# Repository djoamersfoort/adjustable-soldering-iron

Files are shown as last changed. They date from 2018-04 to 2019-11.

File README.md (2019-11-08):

Adjustable Soldering Iron
=========================

An adjustable soldering iron with temperature display using Arduino.
It uses a TM1637Display driver to connect to a 4 digit display.
The temperature is acquired using the MAX6657 thermocouple interface.
Both of these require additional software found below:

- [TM1637 Display library by avischorp](https://github.com/avishorp/TM1637)
- [MAX6675 Thermocouple library by adafruit](https://github.com/adafruit/MAX6675-library)

To install them, download both repositories as a zip file,
and include them using the "Add .ZIP Library" option in the Arduino "Sketch" menu.
To keep the software easy to understand, some nice to have features are not included.

## Hardware

This project is aimed at members of DJO Amersfoort and therefor uses a fairly specific parts configuration.
The soldering iron used is a German 48W/230VAC VTSSC10N/SP made by Velleman.
The schematic is visible below, and is also provided as a pdf file.

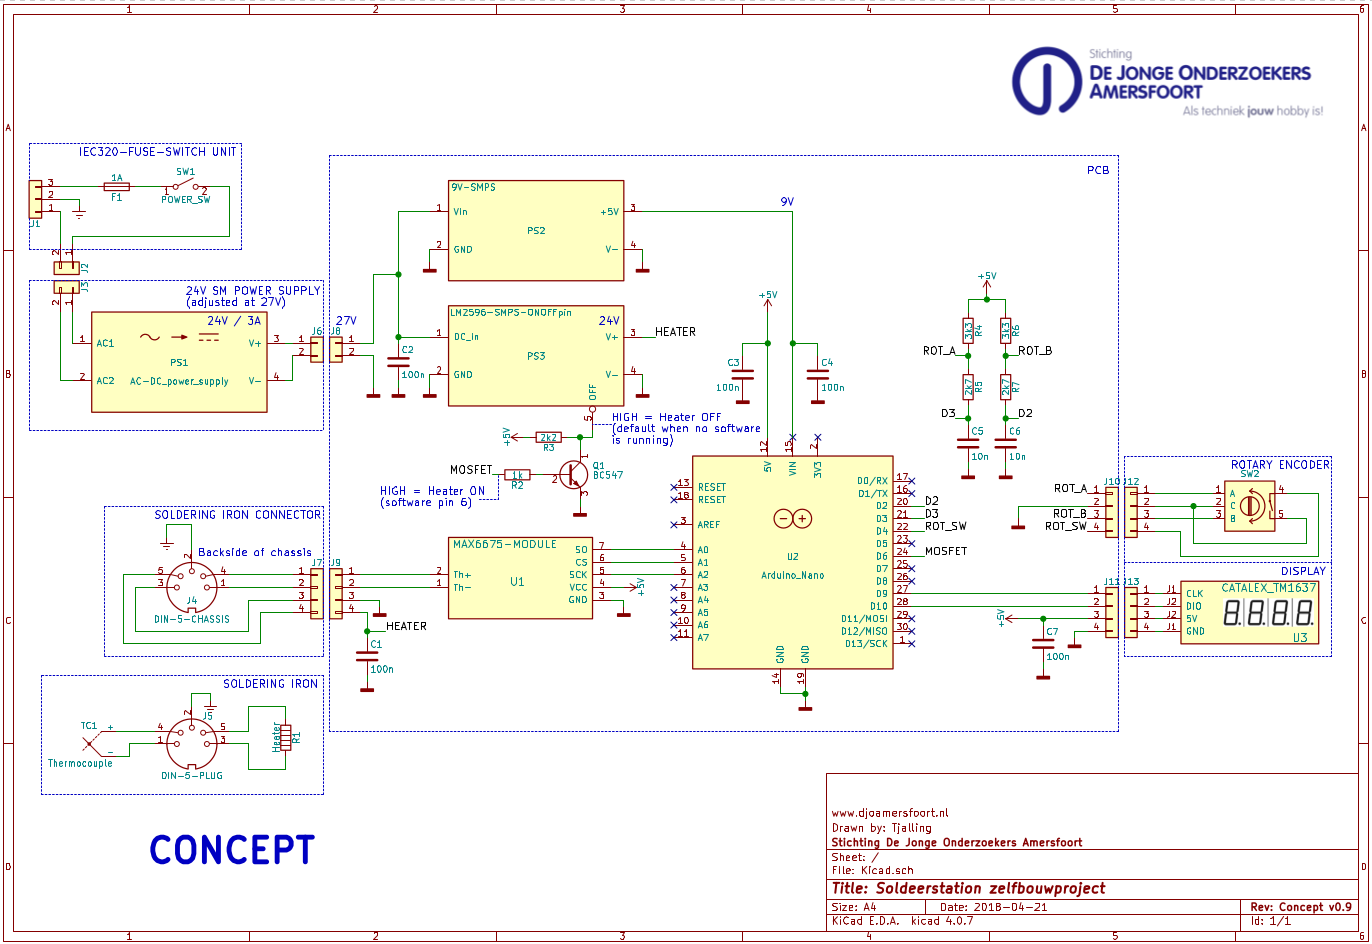
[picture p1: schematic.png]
schematic image


### 3D models

Inside the 3D models folder, there are models for both the case and the parts used for the soldering iron project.
You can use these to build and/or design your own case.

## License

Original concept by:

- Tjalling Brouwer

The software is made by:

- Jelmer van Arnhem ([Github](https://github.com/Jelmerro))
- Camiël vd Niet
- Sieuwe Elferink ([Github](https://github.com/sieuwe1))

The schematic is made by:

- Tjalling Brouwer

The 3d models are made by:

- Huub ([Github](https://github.com/Luxtech))
- Tjalling Brouwer

DJO Amersfoort holds the copyright for all files in this repository,
but they can be copied under the terms of the MIT license, see the LICENSE for details.

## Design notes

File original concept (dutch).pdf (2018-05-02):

Auteur: Tjalling Brouwer

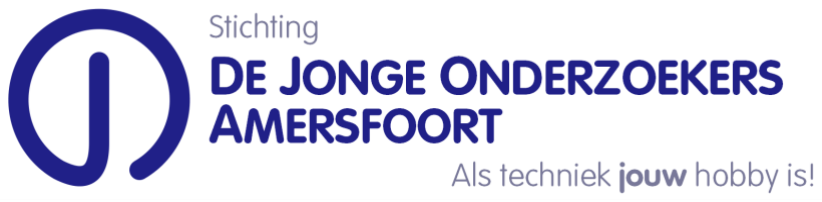
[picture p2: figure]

Oorspronkelijk idee ontwikkeld met Camiël en Hans en uitgewerkt met bijdragen zoals vermeld in Github documenten. Document versie: 2.3

### Idee voor een bouwproject soldeerstation met temperatuurregeling

Een soldeerstation is onmisbaar in een elektronicawerkplaats, of op een hobbytafel voor elektronicaliefhebbers en ICT doe-het-zelfers. Vooral een goed geregelde soldeerbout met voldoende vermogen biedt veel voordelen ten opzichte van de eenvoudige 230V boutjes of soldeerpistolen.

Velleman verkoopt soldeerstations opgebouwd met OEM onderdelen, die voor dit project een inspiratie zijn geweest. Want de soldeerbout zelf is gewoon los te koop. De kwaliteit van deze soldeerbouten is erg goed en er zit een temperatuursensor in. De punten zijn eenvoudig verkrijgbaar in verschillende diktes. Daarnaast zijn de kosten laag, zelfs bij lokale distributeurs.

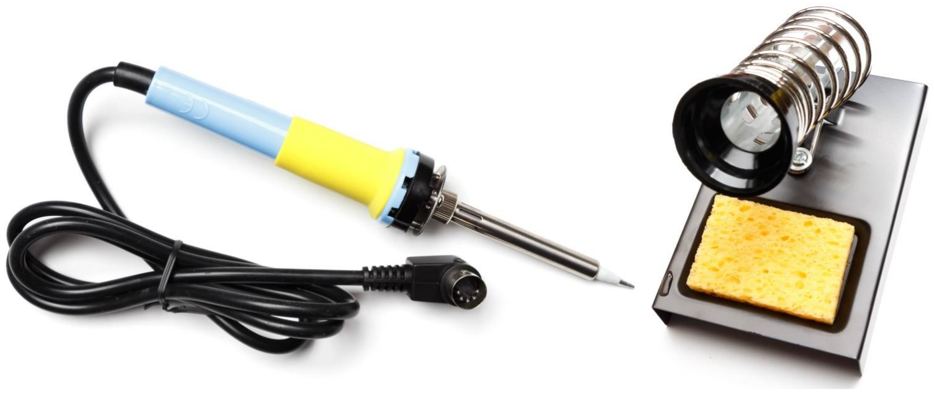
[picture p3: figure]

Er is echter nog wel wat nodig om hier een goed werkend soldeerstation van te maken. Dat maakt dit dan ook een leuk project voor op DJO. De volgende elementen moeten nog toegevoegd worden:

- Temperatuurregeling in een controller, bijvoorbeeld een Arduino
- Software voor de controller
- 24V voeding, een geschakelde voedingsmodule of een transformator (70W minimaal).
- Behuizing: geprint of lasercutter
- Randcomponenten, zoals display, potmeter/rotary switch, zekeringhouder(s), IEC 320 connector, DIN connector, MOSFET switch voor bout, PCB, etc

Controller software en hardware
Een Arduino NANO of UNO zou een goede controller kunnen zijn. Met behulp van begeleiders kunnen DJO leden dan zelf proberen de software te ontwerpen.

Aandachtspunten:

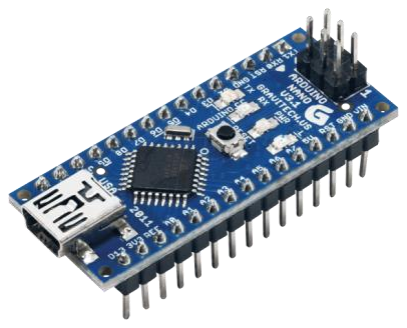
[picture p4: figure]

- In de bout zit een K-type thermocouple om de temperatuur te meten. Door een MAX6675 of een MAX31855 met de seriële uitgang aan te sluiten op de Arduino, kan de temperatuur uitgelezen worden. Een thermocouple meet snel en nauwkeurig.
- Eventueel kan er nog een kalibratieoffset worden opgenomen in de software, als blijkt dat er onderling grote verschillen bestaan tussen de soldeerbouten. Per station kan dan een kalibratie worden gedaan met behulp van een soldeerpunt temperatuurmeter.
- De software moet een hysteresis-lus krijgen, om oscilleren van de MOSFET tegen te gaan op het moment dat het schakelpunt benaderd wordt. Een hysteresis van 5˚C lijkt een redelijke keuze, maar dat kan in de praktijk bepaald worden. Bij een instelling van bijvoorbeeld 370˚C zou de soldeerbout kunnen opwarmen tot de 370˚C gehaald is, om daarna af te schakelen tot gemeten temperatuur 365˚C gehaald heeft. Daarna kan de bout weer
opwarmen tot 370˚C, etc. Na het afschakelen zal de bout nog even
doorgaan met verwarmen. Indien deze overshoot al redelijk groot is (385˚C
bijvoorbeeld), dan kan volstaan worden met een kleinere hysteresis. Finetunen hoort bij de optimalisatie.
- De temperatuurinstelling kan op verschillende manieren gedaan worden.
De leden kunnen hier eigen keuzes in maken. Te denken valt bijvoorbeeld
aan de keuze voor: druktoetsen up-down en/of een rotary encoder. Een

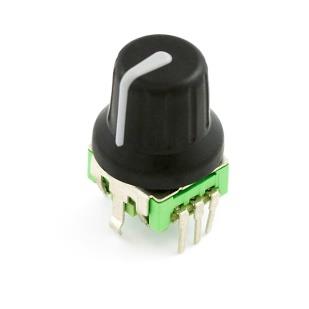
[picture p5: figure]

resolutie van 5˚C is prima en dat maakt ook dat de regeling nog vrij snel gedaan kan worden.
- De laatstgekozen instelling moet bij voorkeur onthouden worden

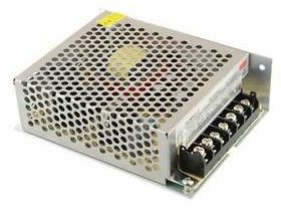
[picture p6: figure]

Voeding
De voeding moet 24V zijn en minimaal 70W (de bout heeft zelf al een opgenomen vermogen van 48W). Standaard werden altijd transformatoren gebruikt. Tegenwoordig zijn er goedkope 24V modules te koop, waar een mooie gestabiliseerde spanning uit komt. Het feit dat dit al gelijkspanning is, is ook wel handig voor gebruik met de controller. Een gelijkrichter is niet meer nodig.

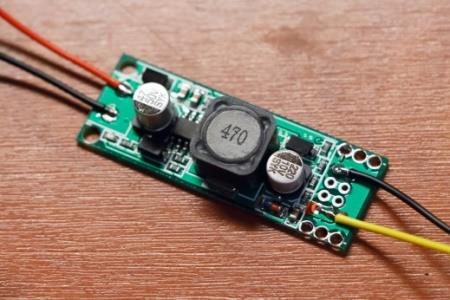
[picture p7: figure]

Wel moet er een spanningsregelaar of een SMPS gebruikt worden tussen 7 en 15V, want 24V is zelfs voor de RAW input (Vin) van de Arduino Nano nog te veel. Deze spanningsregelaar kan dan op de Vin aansluiting worden aangesloten van de Arduino. Let op: sluit deze spanningsregelaar nooit direct aan op de 5V aansluiting van de Arduino Nano, alleen Vin.

Veiligheid is belangrijk, helemaal aan de primaire kant (230V). Goede aansluitingen, zekering en andere veiligheidsmaatregelen moeten in het ontwerp meegenomen worden. Het is ook verstandig om aan de secundaire kant een zekering aan te brengen, nog voor de MOSFET switch en wellicht ook nog een afzonderlijke lichte zekering naar de controller.

Stroombegrenzing
Het verwarmingselement van de door ons gekozen soldeerbout heeft in koude toestand een veel lagere weerstand dan in warme toestand. Daarom heeft een koude soldeerbout een veel hogere stroomopname bij 24V. Pas als de soldeerbout boven ca 250˚C komt, is de stroomopname ca. 2A (bij 24V is dat dus 48Watt aan vermogen). De oorspronkelijk gebruikte transformator had hier niet zoveel last van. Die kon de hogere startstroom wel kortstondig leveren. Maar de door ons gebruikte voedingsmodule moet tegen overbelasting beschermd worden.

De voedingsmodule zal wel een beveiliging hebben, maar die zal de uitgangsspanning gewoon uitschakelen. Dan verwarmd de bout helemaal niet meer en de Arduino krijgt dan ook geen spanning meer.

Dus is er gekozen voor een LM2596 schakelende
spanningsregelaar (SMPS) met stroombegrenzing. Deze kan maximaal 3A leveren. Door de stroombegrenzing op ongeveer 2,8A in te stellen, komt de soldeerbout prima op gang. Een bijkomend voordeel: de LM2596 heeft een ON/OFF-pin, die we mogelijk als schakelaar kunnen gebruiken in plaats van een MOSFET (zie volgende paragraaf). Omdat er wat spanningsverlies optreedt, moet de 24V voeding iets hoger ingesteld worden met de potmeter, ongeveer op 27V.

Elektronische schakelaar voor soldeerboutverwarming

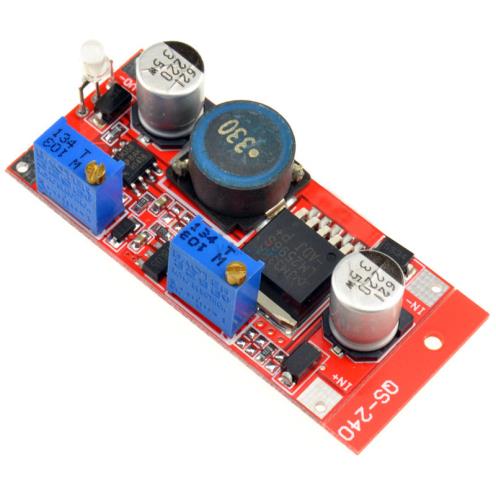
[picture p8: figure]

De soldeerbout zal steeds aan- en uitgeschakeld worden om gemiddeld genomen op de juiste temperatuur te blijven. Deze elektronische schakelaar wordt aangestuurd door de controller en moet de ca. 2A opgenomen stroom van de soldeerbout probleemloos zeer vaak kunnen schakelen in een relatief korte tijd. De schakelaar moet tevens een goede scheiding kunnen garanderen tussen de geschakelde 24V van de soldeerbout en de 5V TTL uit de controller.

Er kan daarom gekozen worden voor een MOSFET als schakelaar. Deze schakeling kan vrij eenvoudig en het type MOSFET komt ook niet zo precies. Er is geen sprake van een PWM/PID regeling, maar gewoon een aan/uit schakeling. Dus ook om die reden is geen speciaal type vereist.

Wel moet de schakeling zodanig ontworpen worden, zodat er weinig invloed is van elektromagnetische velden van buitenaf. De soldeerbout met snoer kan namelijk functioneren als een antenne.

Door de nodige HF ontkoppeling toe te passen, kan de zogenaamde Elektromagnetische Compatibiliteit verbeterd worden. Zie deze link (https://nl.wikipedia.org/wiki/Elektromagnetische_compatibiliteit) en dan vooral het deel over Elektromagnetische

Susceptibiliteit (EMS). Vaak zijn enkele 100nF condensatoren al voldoende. Eventueel kan dit met een smoorspoel nog verder verbeterd worden.

Optie: Mogelijk kan zelfs de ON/OFF-pin (pin 5) van de LM2596 stroombegrenzer gebruikt worden, in plaats van een losse MOSFET. Misschien is het verstandig (omwille van de duurzaamheid) om niet vaker te schakelen dan 1x per seconde maximaal.

Behuizing
De behuizing kan op verschillende manieren gemaakt worden. Er kan een standaard behuizing gekozen worden van stevig kunststof of metaal, of de behuizing kan zelf ontworpen en gemaakt worden met bijvoorbeeld een 3D printer of lasercutter.

Indien een 3D geprinte behuizing gekozen wordt, dan moet het type kunststof stevig en duurzaam zijn. PLA (Polylactide) filament kan daarom beter vermeden worden. Dit is biologisch afbreekbaar. Een soldeerstation heeft vaak een lange levensduur en dan kan dat nadelig uitpakken na enkele jaren van trouwe dienst onder invloed van veel warmte en soms vocht (soldeerspons). Andere typen kunststof, zoals bijvoorbeeld ABS, HIPS, etc, kunnen wel overwogen worden.

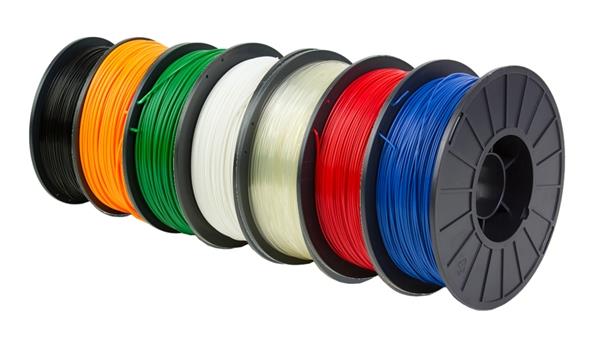
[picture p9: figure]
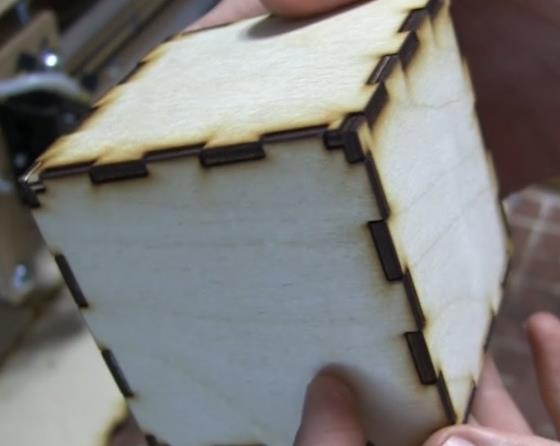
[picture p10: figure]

De behuizing kan echter ook heel goed van 3mm dik MDF gemaakt worden, door met een lasercutter de panelen uit te snijden. Dit kan dan net als de 3D geprinte behuizing zelf ontworpen worden. Indien de behuizing in aanraking kan komen met vochtige sponzen, dan is het verstandig om de behuizing te behandelen met lak. Lakken biedt tevens de mogelijkheid om er een eigen kleur aan te geven, al dan niet in hoogglans. Het MDF moet wel voorbehandeld worden met MDF grondverf, alvorens deze gelakt kan worden met een spuitbus of traditionele lak. Traditionele lak kan het beste met een fijne roller aangebracht worden.

In de lasercutter kunnen ook bepaalde soorten transparante kunststof platen gesneden worden. Op deze manier is het zelfs mogelijk om een transparante behuizing te maken. Er zijn naast heldere doorzichtige platen, ook nog gekleurde platen verkrijgbaar. Dergelijke platen zijn standaard niet op voorraad bij DJO en dienen zelf aangeschaft te worden. Verifieer dan wel bij een begeleider, of het type plaat geschikt is om te snijden met een lasercutter.

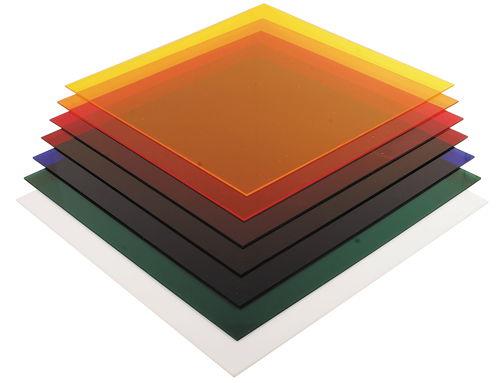
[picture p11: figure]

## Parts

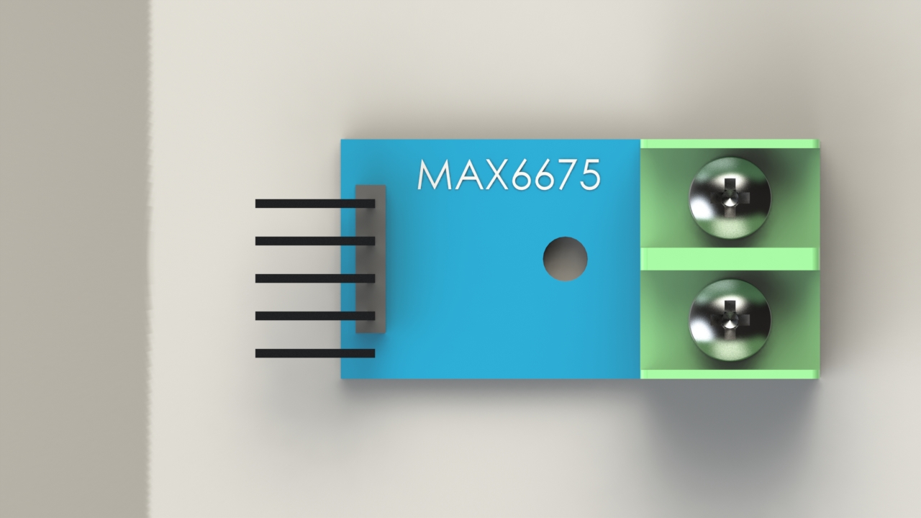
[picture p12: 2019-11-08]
3D models/Parts/MAX6675-K/MAX6675-K2.JPG

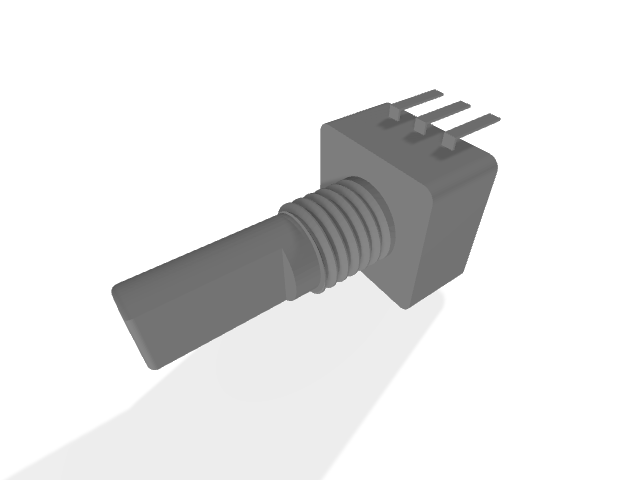
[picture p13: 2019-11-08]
3D models/Parts/Rotary Encoder/Rotary-Encoder.png

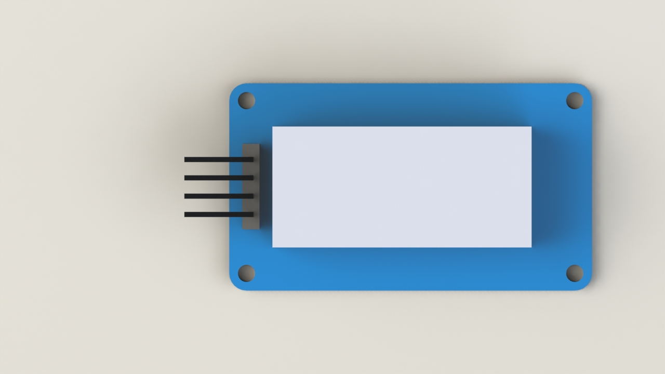
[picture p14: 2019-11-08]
3D models/Parts/4-digit Display/4-digit Display2.JPG

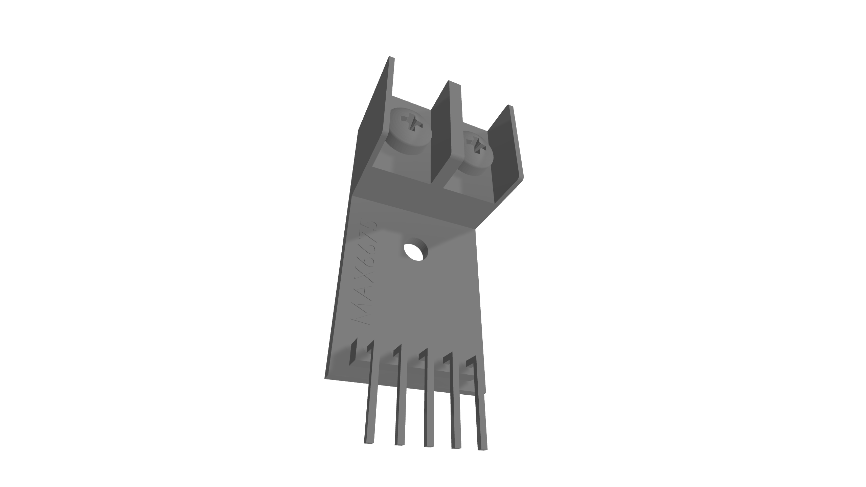
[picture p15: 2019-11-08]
3D models/Parts/MAX6675-K/MAX6675-K.png

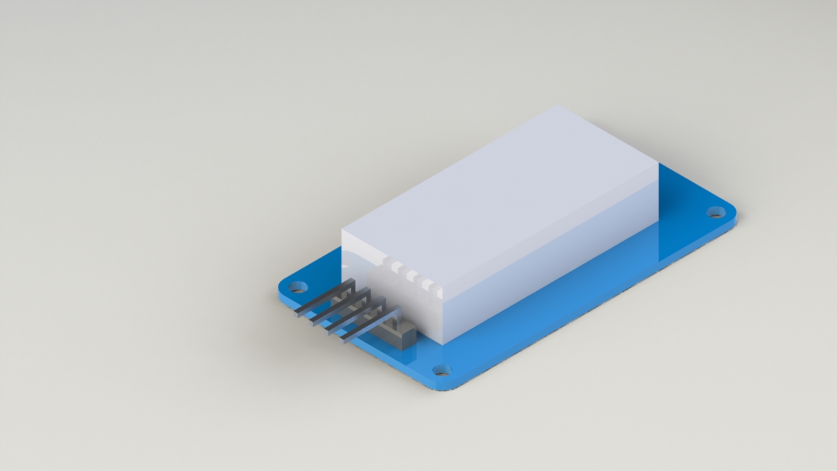
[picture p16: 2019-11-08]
3D models/Parts/4-digit Display/4-digit Display.JPG

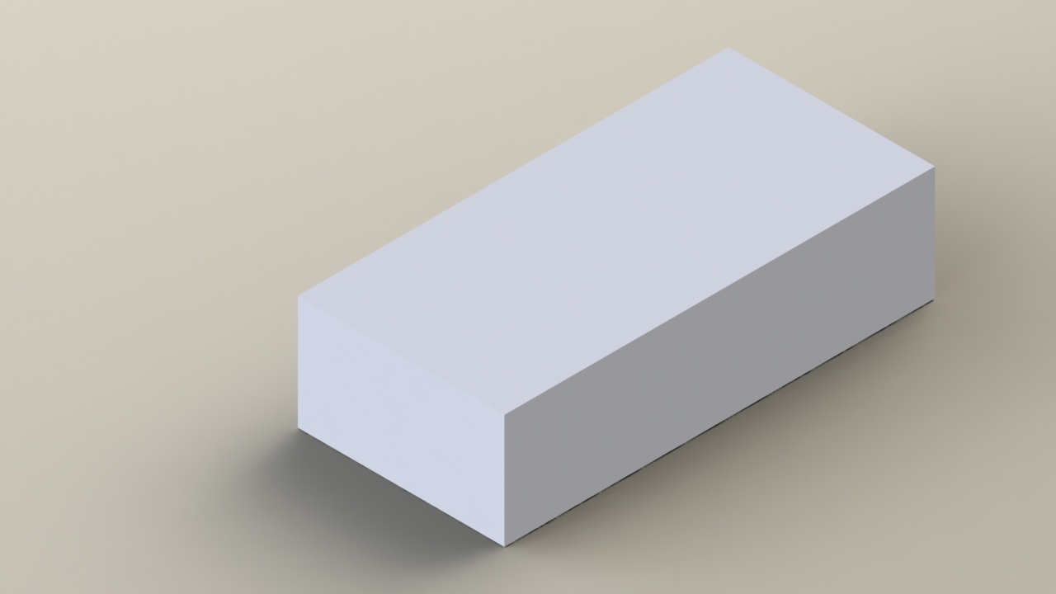
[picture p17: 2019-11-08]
3D models/Parts/LM2596 Place holder/LM2596 Place holder.JPG

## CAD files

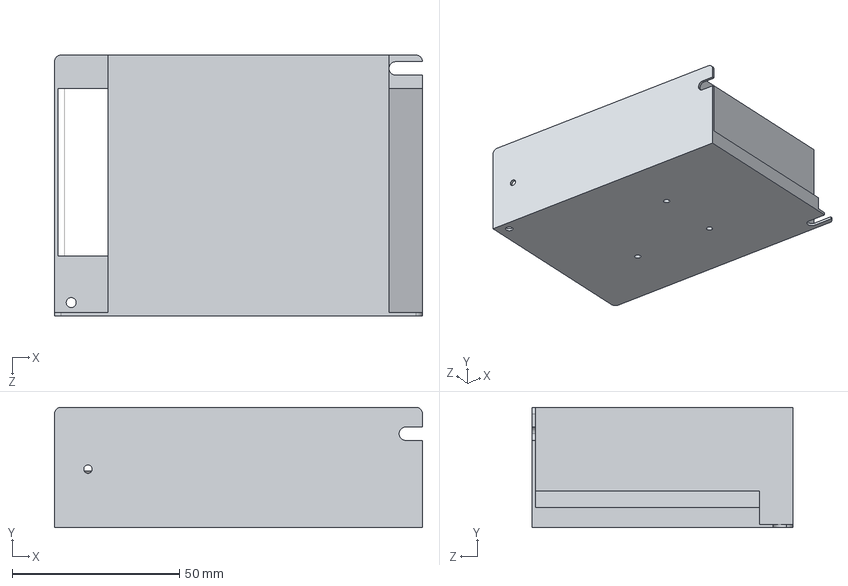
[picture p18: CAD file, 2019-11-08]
3D models/Parts/PSU/STEP/PSU Assembly.STEP
110.0 x 36.0 x 78.0 mm
case
conntectorblock
pan head cross recess screw_iso_ISO 7045 - M4 x 5 - Z - 5N x 5
Screen connectorblock

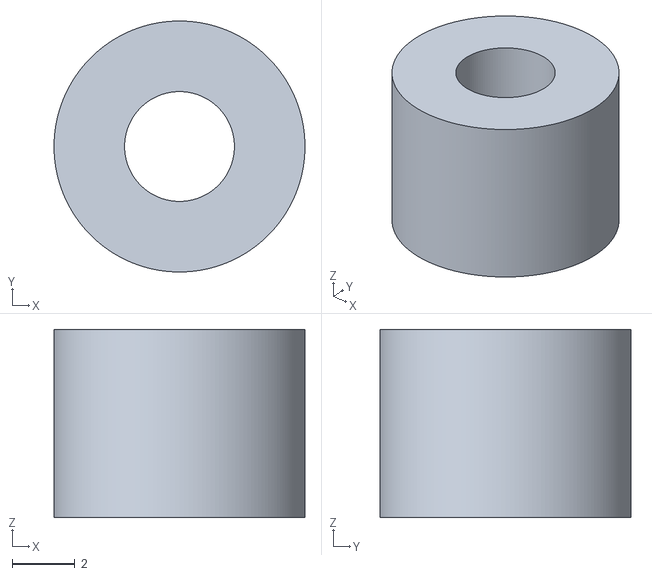
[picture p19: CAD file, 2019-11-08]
3D models/Case/Baseplate/Standoff-one.stl
8.00 x 8.00 x 6.00

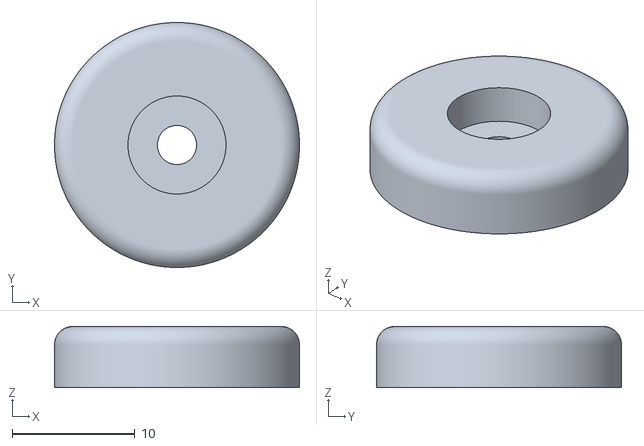
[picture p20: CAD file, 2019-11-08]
3D models/Case/Feet/Feet-one.stl
20.0 x 20.0 x 5.00

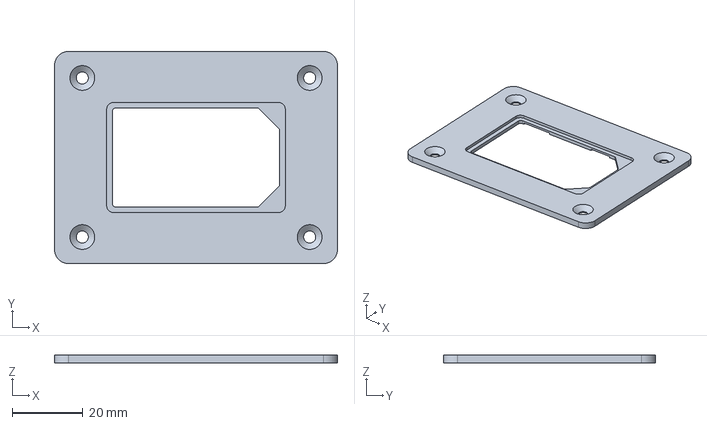
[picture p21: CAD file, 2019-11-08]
3D models/Case/IEC320-backplate-for-woodpanels-large/FreeCAD/IEC320 backplate-for woodpanels-large.FCStd
80.0 x 60.0 x 2.20 mm

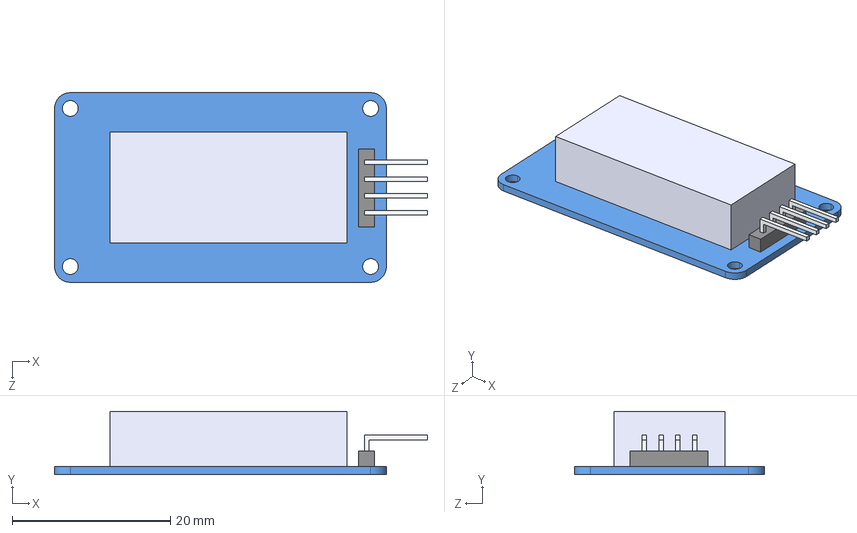
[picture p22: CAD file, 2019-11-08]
3D models/Parts/4-digit Display/STEP/4-digit Display.STEP
47.2 x 8.00 x 24.0 mm
PCB
7segment display
Header-Base
Header-Pin x 4

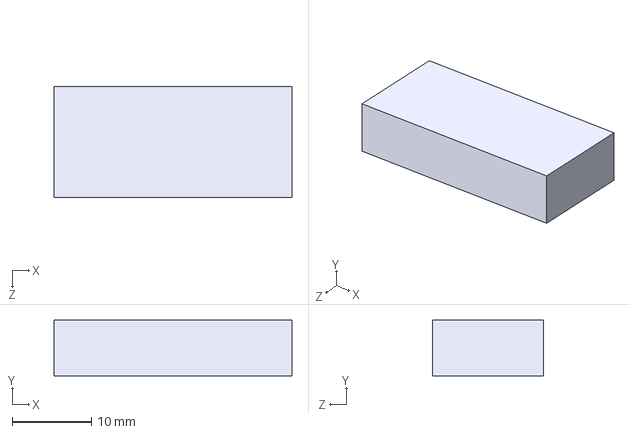
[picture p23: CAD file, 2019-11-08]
3D models/Parts/4-digit Display/STEP/STEP Separate parts/7segment display.STEP
30.0 x 7.00 x 14.0 mm

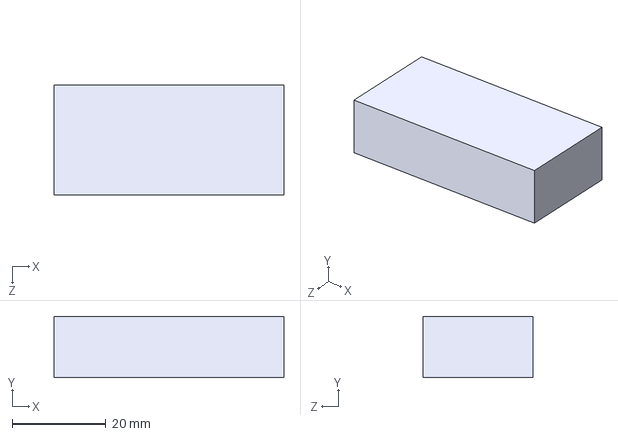
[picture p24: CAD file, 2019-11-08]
3D models/Parts/LM2596 Place holder/STEP/LM2596 Place holder.STEP
49.0 x 13.0 x 23.5 mm

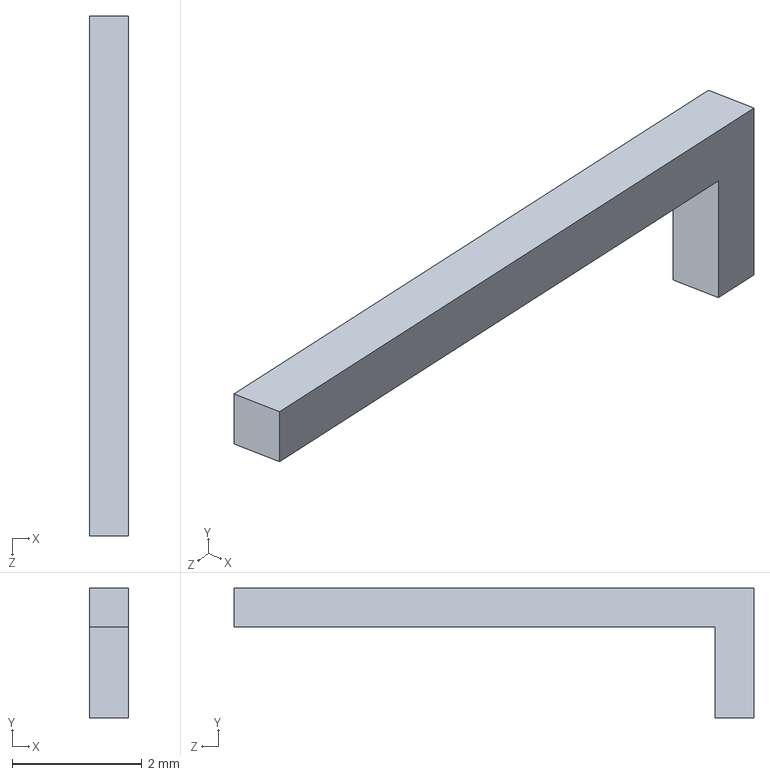
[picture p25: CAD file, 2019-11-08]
3D models/Parts/MAX6675-K/SOLIDWORKS/SOLIDWORKS Separate parts/Header-Pin.SLDPRT
0.6 x 2.00 x 8.00 mm

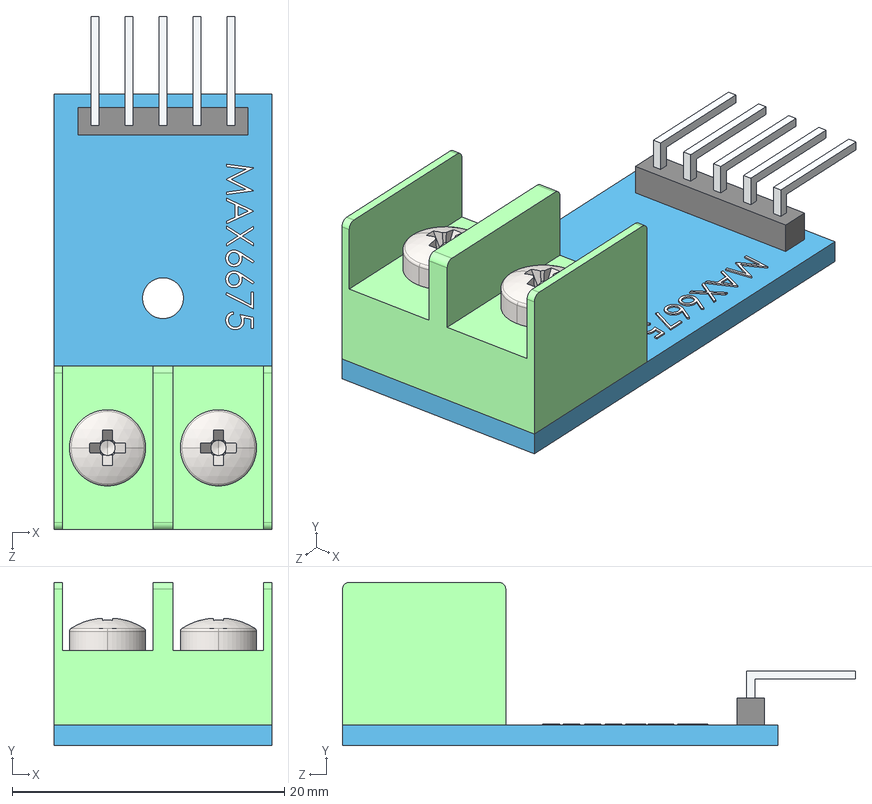
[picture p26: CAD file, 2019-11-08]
3D models/Parts/MAX6675-K/STEP/MAX6675-K.STEP
16.0 x 12.0 x 37.7 mm
MAX6675-K PCB
MAX6675-K Connector-Block Base
pan head cross recess screw_iso_ISO 7045 - M3 x 4 - Z - 4N x 2
Header-Base
Header-Pin x 5

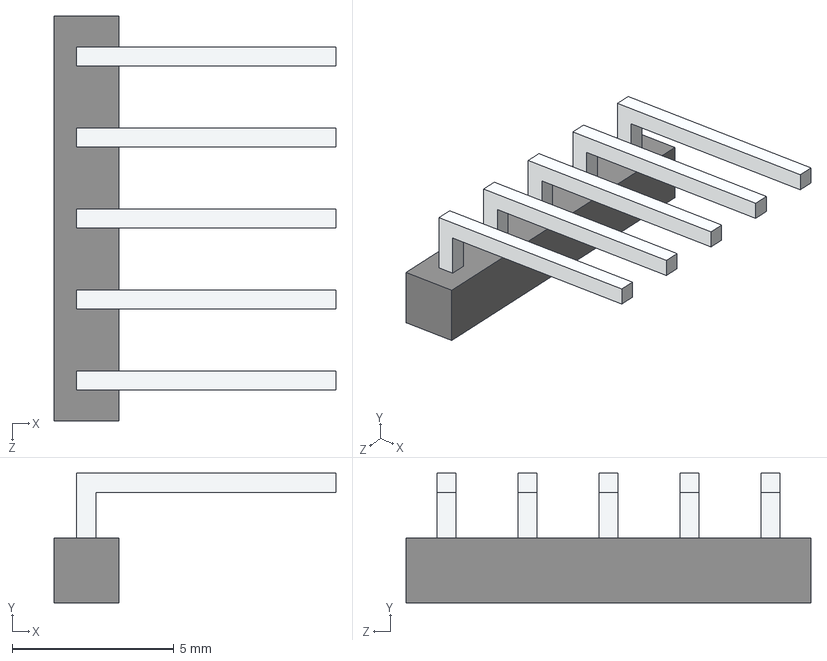
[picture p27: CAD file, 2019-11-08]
3D models/Parts/MAX6675-K/STEP/STEP Separate parts/MAX6675-K Header.STEP
8.70 x 4.00 x 12.5 mm
Header-Base
Header-Pin x 5

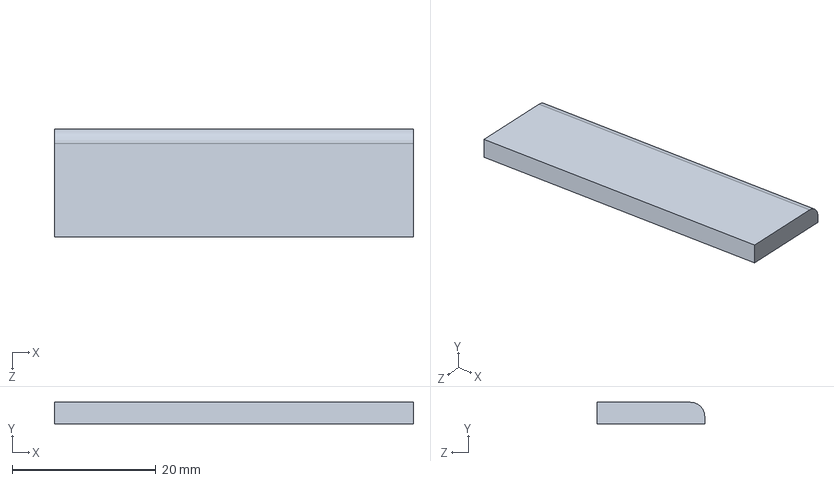
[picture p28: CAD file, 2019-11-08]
3D models/Parts/PSU/SOLIDWORKS/SOLIDWORKS Separate parts/Screen connectorblock.SLDPRT
50.0 x 3.00 x 15.0 mm

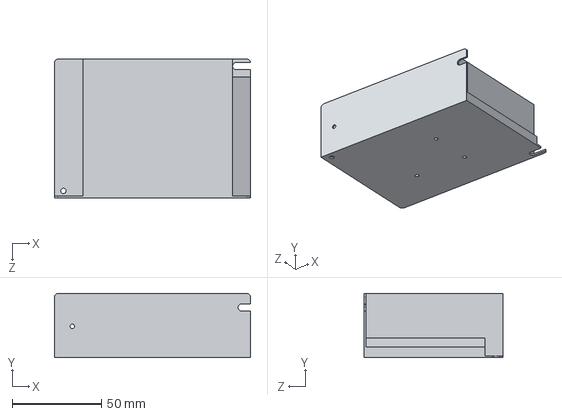
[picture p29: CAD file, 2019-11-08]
3D models/Parts/PSU/STEP/STEP Separate parts/case.STEP
110.0 x 36.0 x 78.0 mm

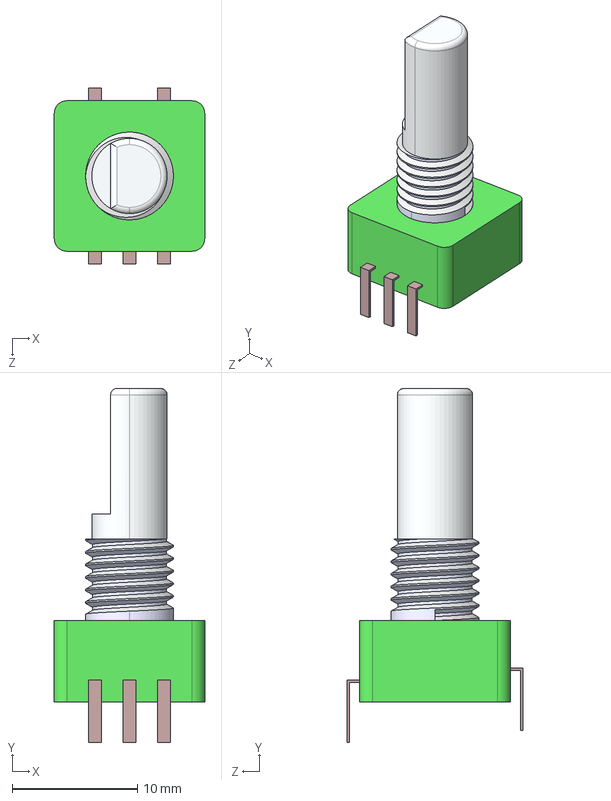
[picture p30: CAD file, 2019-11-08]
3D models/Parts/Rotary Encoder/STEP/Rotary-Encoder.STEP
12.0 x 28.2 x 14.0 mm
Rotary-Encoder Base
Rotary-Encoder Pin x 5
Rotary-Encoder knop

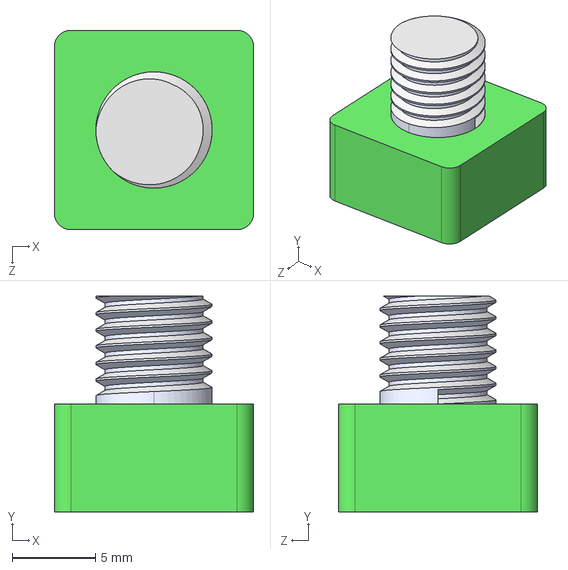
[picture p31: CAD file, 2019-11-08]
3D models/Parts/Rotary Encoder/STEP/STEP Separate parts/Rotary-Encoder Base.STEP
12.0 x 13.0 x 12.0 mm

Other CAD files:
Box/BoxFront.dxf
3D models/Case/Baseplate/Baseplate.stl
3D models/Parts/4-digit Display/STEP/STEP Separate parts/Header-Base.STEP
3D models/Case/Baseplate/Fusion360/baseplate.f3d
3D models/Case/IEC320-backplate-for-woodpanels-large/IEC320 backplate-for woodpanels-large.stl
3D models/Parts/4-digit Display/SOLIDWORKS/4-digit Display.SLDASM
3D models/Parts/4-digit Display/SOLIDWORKS/SOLIDWORKS Separate parts/7segment display.SLDPRT
3D models/Parts/4-digit Display/SOLIDWORKS/SOLIDWORKS Separate parts/Header-Base.SLDPRT
3D models/Parts/4-digit Display/SOLIDWORKS/SOLIDWORKS Separate parts/Header-Pin.SLDPRT
3D models/Parts/4-digit Display/SOLIDWORKS/SOLIDWORKS Separate parts/Header.SLDASM
3D models/Parts/4-digit Display/SOLIDWORKS/SOLIDWORKS Separate parts/PCB.SLDPRT
3D models/Parts/4-digit Display/STEP/STEP Separate parts/Header-Pin.STEP
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

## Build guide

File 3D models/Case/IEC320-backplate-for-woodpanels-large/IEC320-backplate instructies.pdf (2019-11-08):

IEC 320 unit achterplaat voor kunststof en houten behuizingen

Ontwerp: FreeCAD, door Tjalling, 6 maart 2018 Bestandsnaam: IEC320 backplate-for woodpanels-large.FCStd

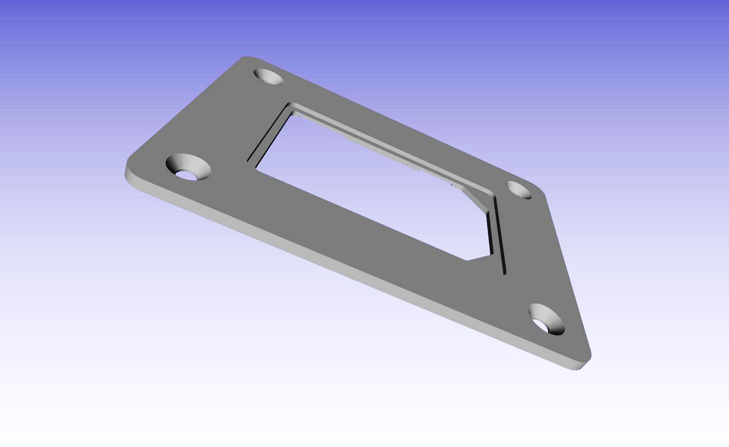
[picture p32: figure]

Voor de slicer software worden de volgende instellingen geadviseerd:

- Zet de layer height niet hoger dan 0,1mm, omdat de clipjes aan de binnenzijde veel krachten moeten kunnen doorstaan.
- Printspeed niet hoger dan 40mm/s.
- Ondanks de kleine “overhang” in de clipjes, gebruik toch geen support.
- Zet om die reden de ventilator iets bovengemiddeld voor ABS, of op 100% voor PLA.
- Zet de print temperatuur iets hoger om de laaghechting te vergroten.
- Print bij voorkeur zonder infill.

Printtijd: ca. 1,5 uur

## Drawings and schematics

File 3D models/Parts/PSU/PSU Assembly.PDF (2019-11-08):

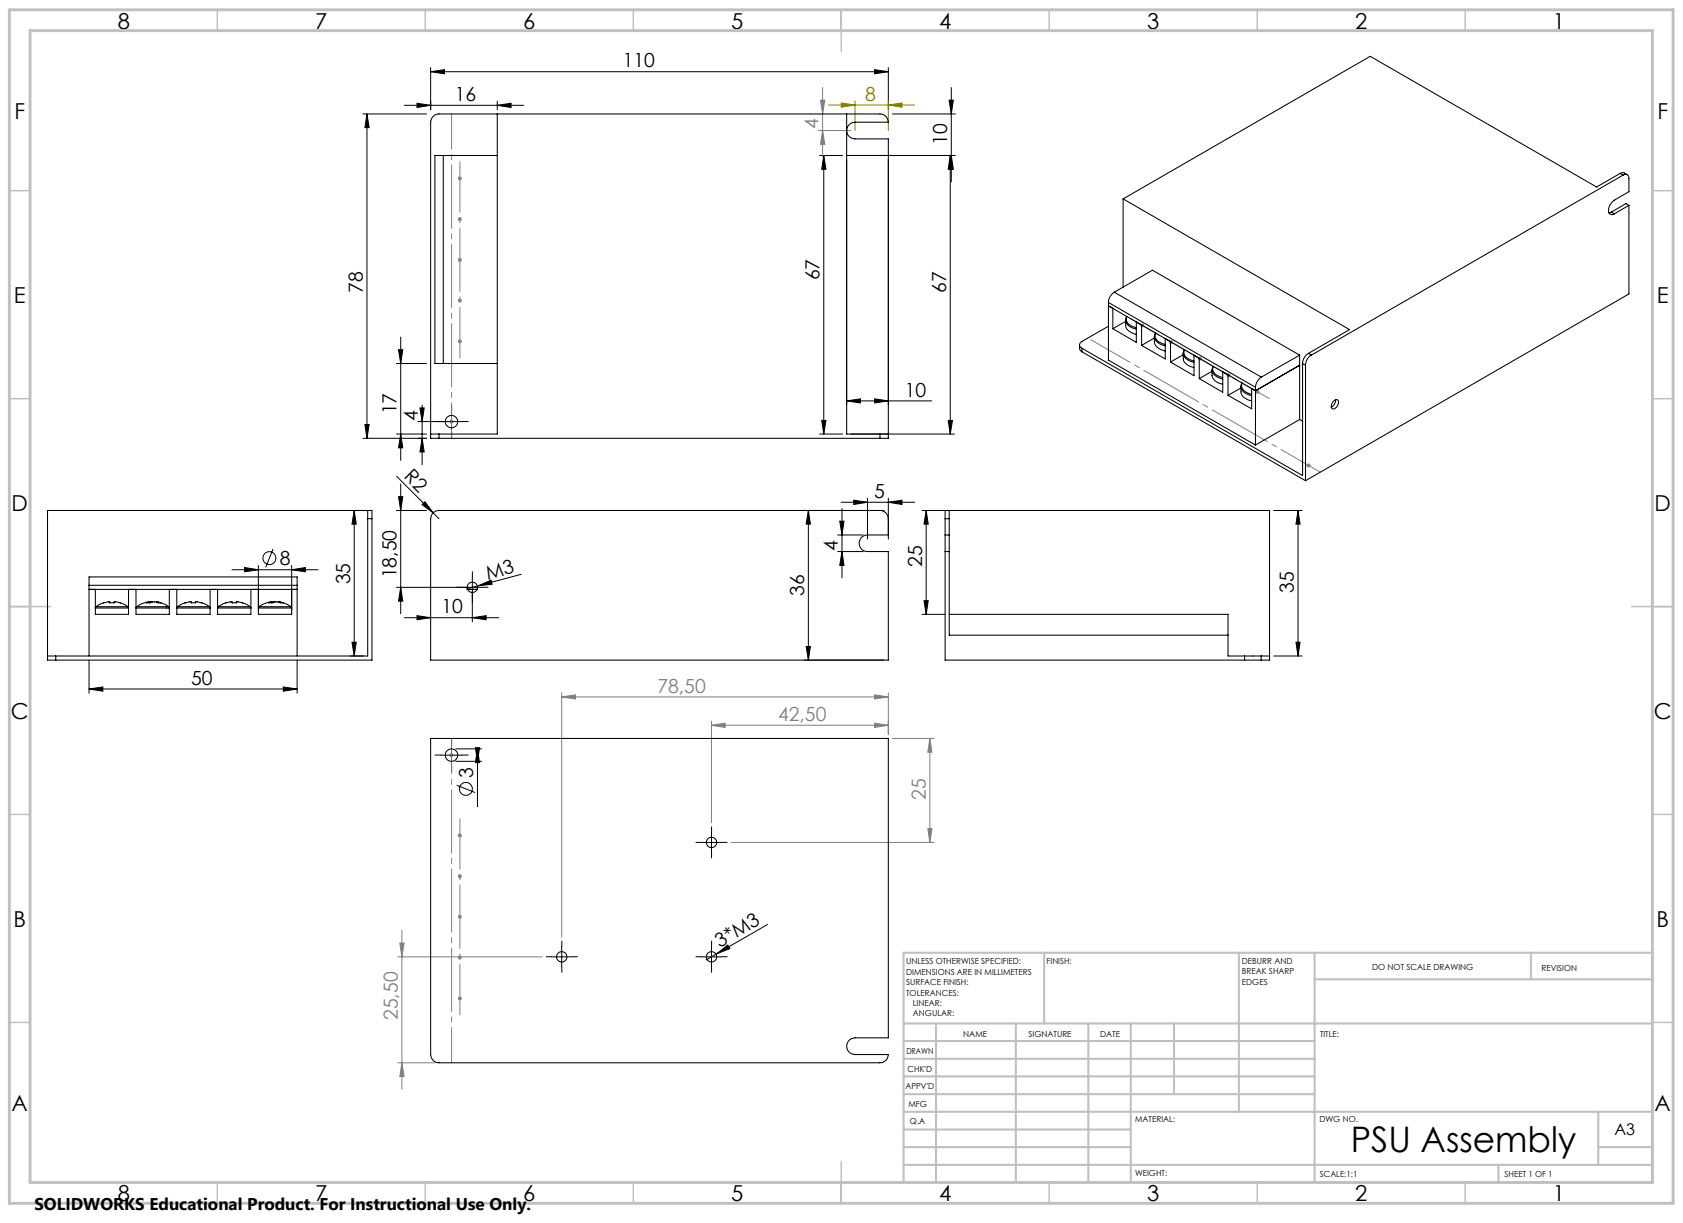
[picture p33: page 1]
FINISH:; DEBURR AND; BREAK SHARP; DO NOT SCALE DRAWING; REVISION; SCALE:1:1; SHEET 1 OF 1

UNLESS OTHERWISE SPECIFIED:
DIMENSIONS ARE IN MILLIMETERS
SURFACE FINISH:
TOLERANCES:
LINEAR:
ANGULAR:

NAME | SIGNATURE | DATE | | | | TITLE:

DRAWN
CHK'D
APPV'D
MFG
Q.A | | | | MATERIAL: | DWG NO. PSU Assembly | A3

SOLIDWORKS Educational Product. For Instructional Use Only.

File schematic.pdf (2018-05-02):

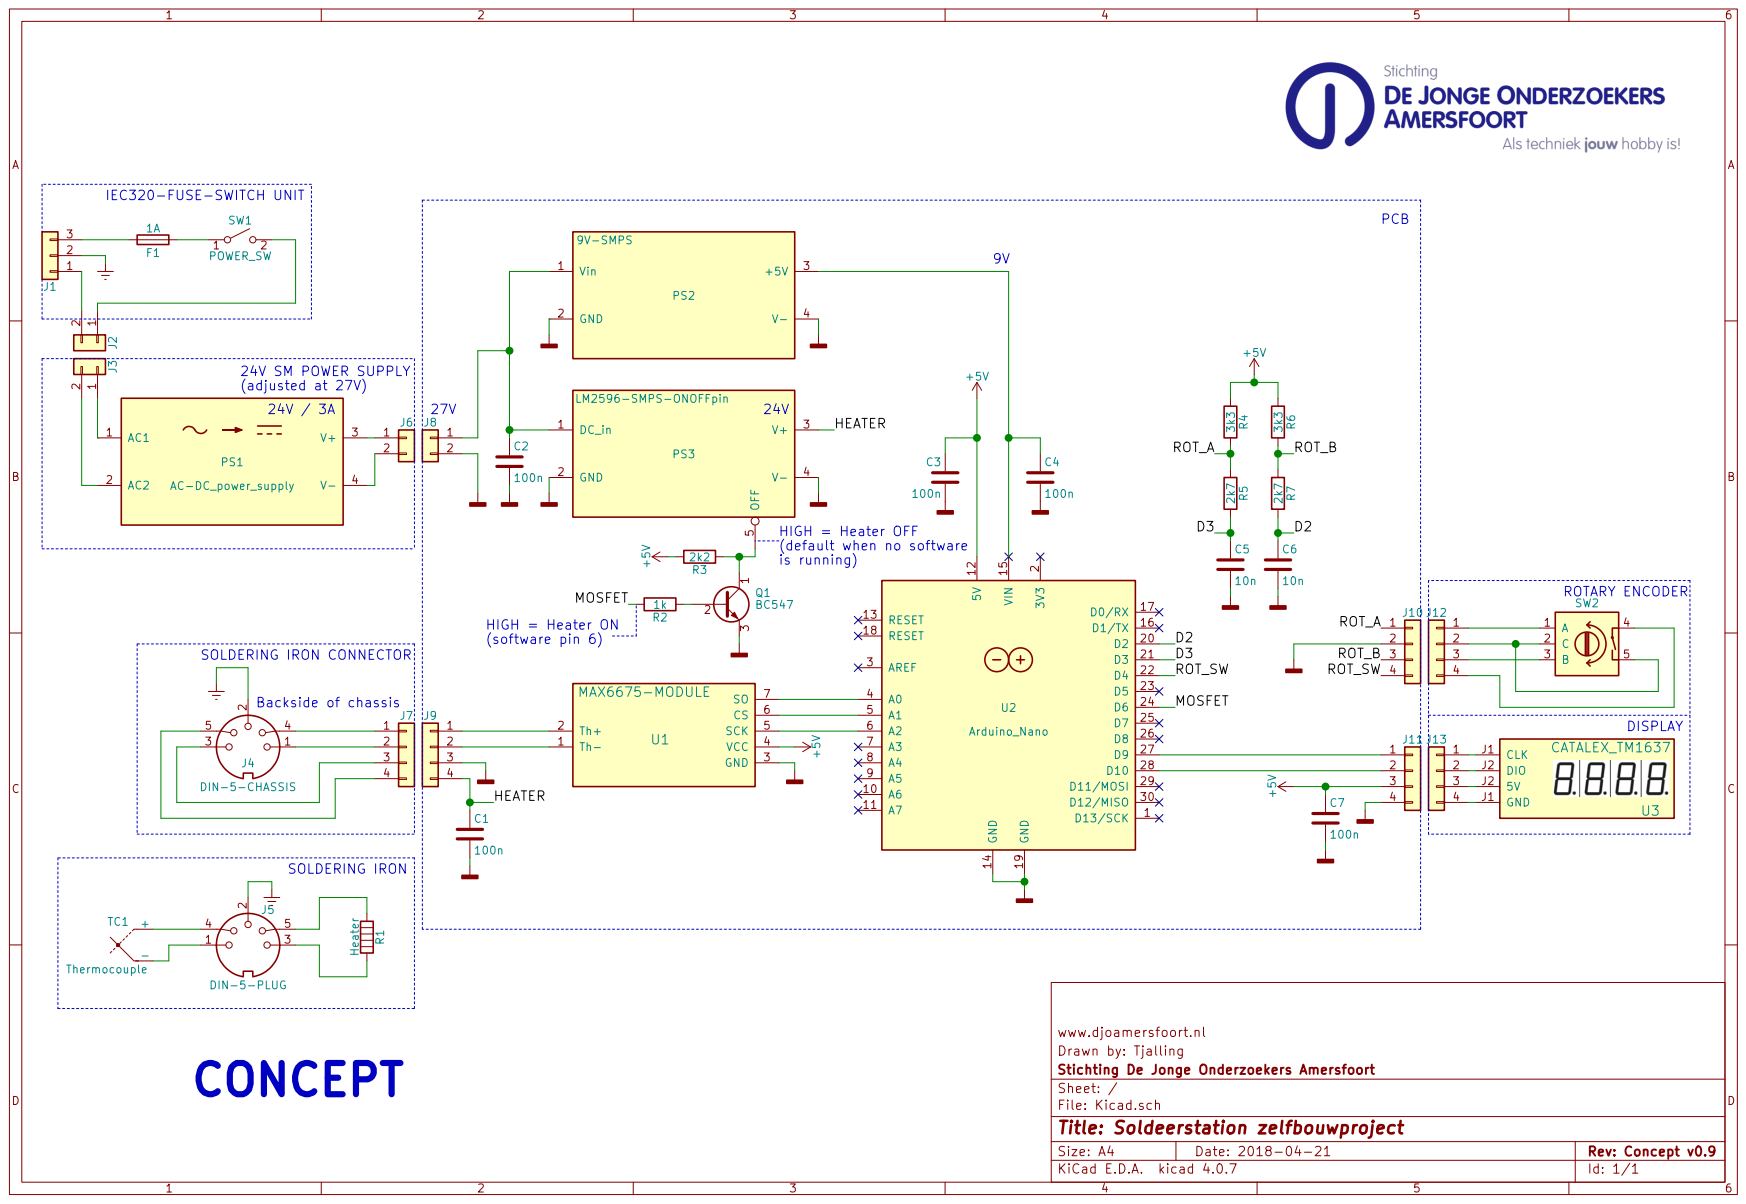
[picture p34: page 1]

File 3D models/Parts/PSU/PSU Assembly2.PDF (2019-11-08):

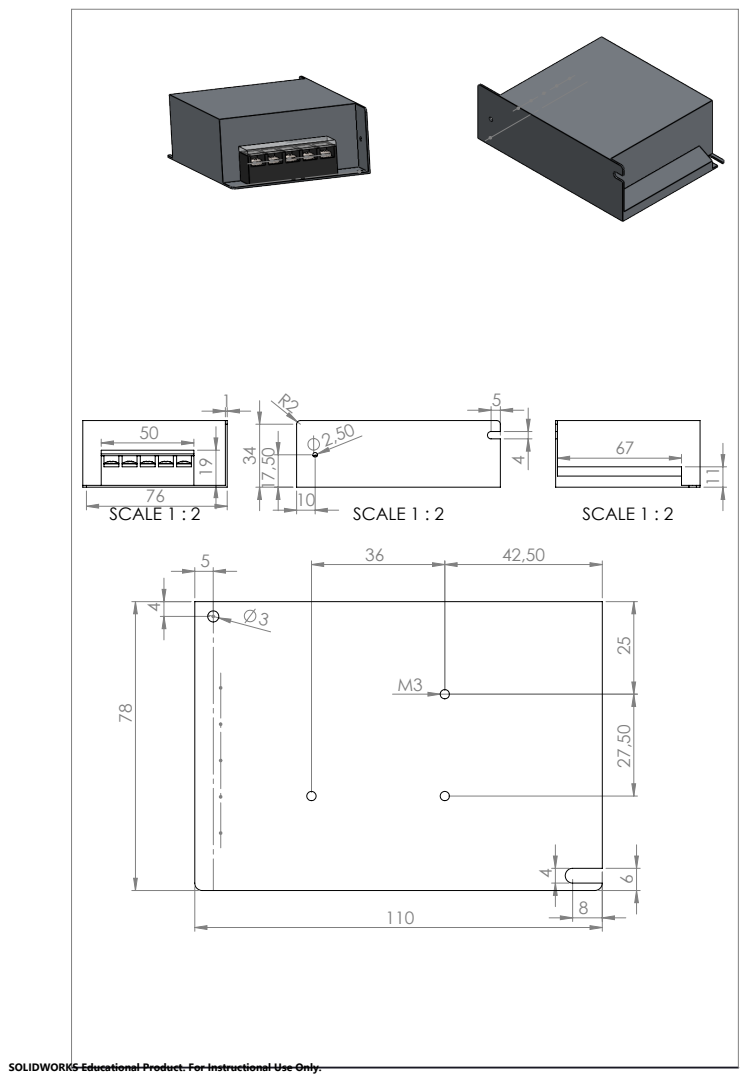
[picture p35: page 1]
SCALE 1 : 2

SOLIDWORKS Educational Product. For Instructional Use Only.

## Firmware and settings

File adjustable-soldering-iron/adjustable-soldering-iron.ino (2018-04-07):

//Adjustable soldering iron
//Software written by:
// - Jelmer van Arnhem
// - Camiël vd Niet
// - Sieuwe Elferink
//Copyright (c) 2018 DJO Amersfoort
//MIT Licensed


//Display library
//https://github.com/avishorp/TM1637
#include <TM1637Display.h>
//Temperature library
//https://github.com/adafruit/MAX6675-library
#include <max6675.h>


//Customise your stuff here
double curveValue = 0.5;
int roundTemperatureValue = 5;
int temperatureReadDelay = 500;
int configuredTemperature = 350;


//Pins
int rotaryClockPin = 2;
int rotaryDataPin = 3;
int rotaryToggleButtonPin = 4;
int mosfetPin = 6;
int displayClockPin = 9;
int displayDataPin = 10;
int thermoSOPin = A0;
int thermoCSPin = A1;
int thermoClockPin = A2;


//Other variables
unsigned long temperatureReadTimer;
int valueToDisplay = 0;
int currentTemp = 0;
bool showActualTemp = true;
bool rotaryButtonIsReleased = true;
int rotaryState = 0;
int rotaryPrevState = 0;
int nextEncoderState[4] = { 2, 0, 3, 1 };
int prevEncoderState[4] = { 1, 3, 0, 2 };


//Initialise components
TM1637Display display(displayClockPin, displayDataPin);
MAX6675 thermocouple(thermoClockPin, thermoCSPin, thermoSOPin);


void setup() {
  //Activate the display
  for (byte i = 0; i < 4; i++) {
    display.setSegments(0, 1, i);
  }
  display.setBrightness(0x0C);
  //Activate the pins
  pinMode(mosfetPin, OUTPUT);
  pinMode(rotaryClockPin, INPUT);
  pinMode(rotaryDataPin, INPUT);
  pinMode(rotaryToggleButtonPin, INPUT_PULLUP);
  digitalWrite(mosfetPin, HIGH);
  digitalWrite(rotaryDataPin, HIGH);
  digitalWrite(rotaryClockPin, HIGH);
  //Start temperature timer
  temperatureReadTimer = millis();
}


void loop() {
  //Update the current temperature on a slow timer (not every loop)
  if (millis() > temperatureReadTimer + temperatureReadDelay) {
    updateActualTemp();
  }
  //Toggle between actual current temperature and the configured temperature
  if (digitalRead(rotaryToggleButtonPin) == HIGH) {
    rotaryButtonIsReleased = true;
  } else {
    if (rotaryButtonIsReleased) {
      showActualTemp = !showActualTemp;
      rotaryButtonIsReleased = false;
    }
  }
  //Show the actual current temperature or the configured temperature
  if (showActualTemp) {
    display.showNumberDec(currentTemp);
  } else {
    updateConfiguredTemp();
    display.showNumberDec(configuredTemperature, true);
  }
  //Enable or disable the soldering iron
  if (currentTemp >= configuredTemperature) {
    digitalWrite(mosfetPin, LOW);
  } else {
    digitalWrite(mosfetPin, HIGH);
  }
}


void updateConfiguredTemp() {
  //Read the configured temperature from the rotary
  rotaryState = (digitalRead(rotaryClockPin) << 1) | digitalRead(rotaryDataPin);
  if (rotaryState != rotaryPrevState) {
    if (rotaryState == nextEncoderState[rotaryPrevState]) {
      configuredTemperature = configuredTemperature + 5;
    } else if (rotaryState == prevEncoderState[rotaryPrevState]) {
      configuredTemperature = configuredTemperature - 5;
    }
    if (configuredTemperature > 420) {
      configuredTemperature = 420;
    }
    if (configuredTemperature < 0) {
      configuredTemperature = 0;
    }
    rotaryPrevState = rotaryState;
  }
}


void updateActualTemp() {
  //read and round the temperature
  int celsius = thermocouple.readCelsius();
  currentTemp = round(celsius * curveValue * roundTemperatureValue) / roundTemperatureValue;
  temperatureReadTimer = millis();
}

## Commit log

2018-04-07 improved pin layout and inverted mosfet output
    [adjustable-soldering-iron.ino]
2018-04-11 added schematic and improved readme
2018-05-02 added original concept + updated schematic
2019-11-08 add better 3d models
    [4-digit Display.SLDASM, 4-digit Display.STEP, 4-digit Display.STL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]
2020-01-24 Add lasercut box
    [BoxBack.dxf, BoxBottom.dxf, BoxFront.dxf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]
